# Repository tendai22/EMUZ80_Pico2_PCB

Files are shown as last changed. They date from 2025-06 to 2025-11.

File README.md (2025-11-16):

# EMUZ80_Pico2_PCB
KiCad PCB for emuz80_pico2

## WeAct RP2350B Core Board での動作

GPIO23を D7 に割り当てているが、D7 だけ L に落ちてくれない。

一瞬 L になるが、次の瞬間に H に戻っている。

blink で GPIO23 を指定したときは動作している。

Pimoroni 2350 の試作基板では動作している。

ハードウェアの違いによると考えられる。

基板の配線違いか、5.1kΩのプルアップが悪さをしていると考えた。

導通を見る限り怪しいところとつながっている様子はない。

結局 5.1kΩプルアップ抵抗をちぎり取って動作するようになった。なんとも。

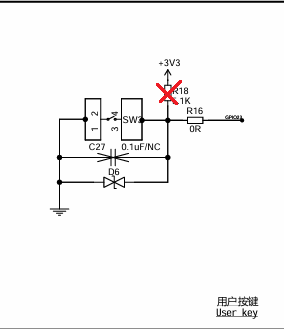
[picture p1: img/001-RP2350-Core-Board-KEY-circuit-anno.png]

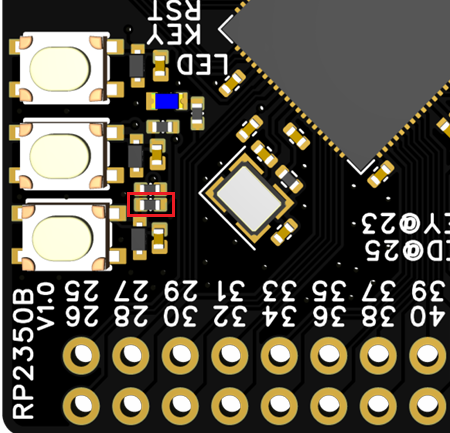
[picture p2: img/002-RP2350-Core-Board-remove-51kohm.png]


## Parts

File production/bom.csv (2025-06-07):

Designator | Footprint | Quantity | Value | LCSC Part #
C1, C2, C3, C4, C5 | C_Disc_D3.0mm_W1.6mm_P2.50mm | 5 | 0.1u
C7 | CP_Radial_D5.0mm_P2.50mm | 1 | 10uF
D1, D5 | D_DO-34_SOD68_P7.62mm_Horizontal | 2 | 1S3
D2 | LED_D3.0mm | 1 | RED
D3 | LED_D3.0mm | 1 | GREEN
D4 | LED_D3.0mm | 1 | YELLOW
J3 | PinHeader_1x08_P2.54mm_Vertical | 1 | EXT_GPIO1
J4 | PinHeader_1x02_P2.54mm_Vertical | 1 | EXT_GPIO2
J5 | PinHeader_1x06_P2.54mm_Horizontal_NoFeet | 1 | Serial
J6 | USB_Micro-B_Hirose_ZX62-B-5PA | 1 | USB_B_Micro
J8 | PinHeader_1x05_P2.54mm_Vertical | 1 | Conn_01x05_Pin
JP1 | SolderJumper-2_P1.3mm_Bridged_RoundedPad1.0x1.5mm | 1 | VCC_Jumper
JP2 | SolderJumper-2_P1.3mm_Bridged_RoundedPad1.0x1.5mm | 1 | CE1_J
JP3 | SolderJumper-2_P1.3mm_Bridged_RoundedPad1.0x1.5mm | 1 | CS2_J
JP4 | SolderJumper-2_P1.3mm_Bridged_RoundedPad1.0x1.5mm | 1 | OE_J
JP5 | SolderJumper-2_P1.3mm_Bridged_RoundedPad1.0x1.5mm | 1 | WE_J
R1, R2, R3 | R_Axial_L5.5mm_D2.0mm_P7.62mm_Horizontal | 3 | 1k
R4 | R_Axial_L5.5mm_D2.0mm_P7.62mm_Horizontal | 1 | 10k
SW1 | Tact_SW | 1 | RUN
SW2 | Tact_SW | 1 | BOOTSEL
U1 | PLCC-64_THT-Socket | 1 | Pimoroni PGA2350B
U2 | RB2350B_Core_Board | 1 | RB2350B_Core_Board
U3 | DIP-14_W7.62mm_Socket | 1 | 74HC00
U4 | DIP-40_SidePin_Z80 | 1 | Z80CPU
U5 | DIP-32_W15.24mm_OvalPads | 1 | HM628128

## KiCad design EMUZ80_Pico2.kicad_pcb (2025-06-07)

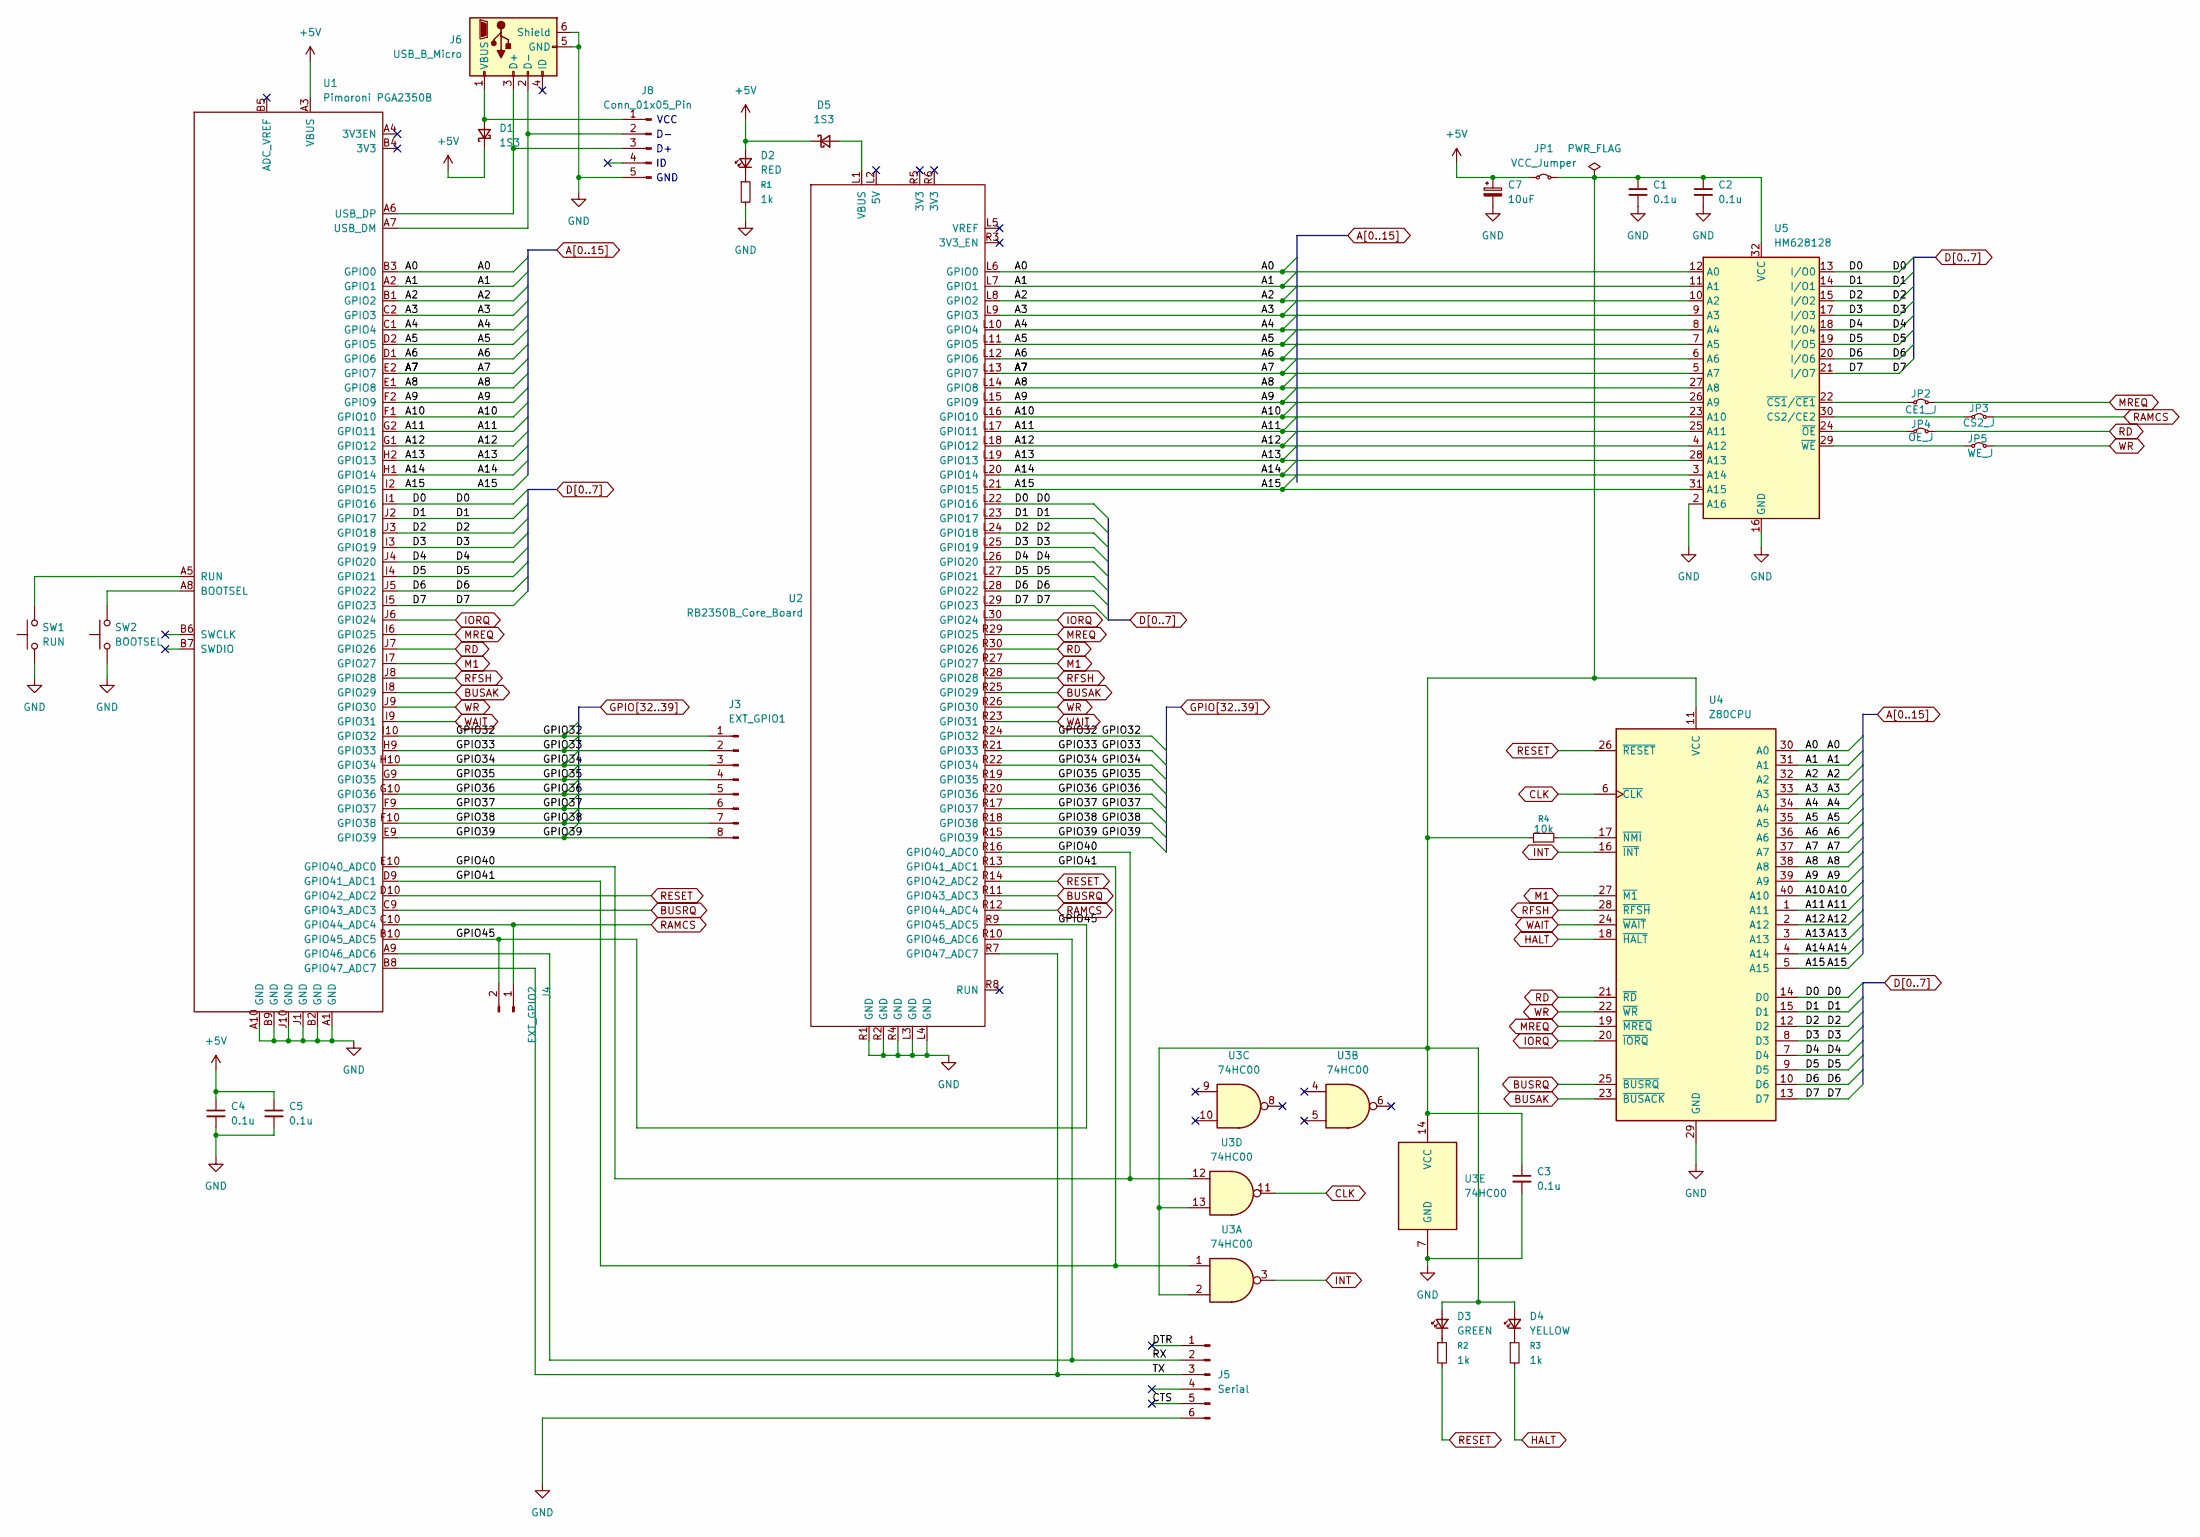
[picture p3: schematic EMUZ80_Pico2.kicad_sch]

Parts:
C1, C2, C3, C4, C5: 0.1u; C_Disc_D3.0mm_W1.6mm_P2.50mm
C7: 10uF; CP_Radial_D5.0mm_P2.50mm
D1, D5: 1S3; D_DO-34_SOD68_P7.62mm_Horizontal
D2: RED; LED_D3.0mm
D3: GREEN; LED_D3.0mm
D4: YELLOW; LED_D3.0mm
J3: EXT_GPIO1; PinHeader_1x08_P2.54mm_Vertical
J4: EXT_GPIO2; PinHeader_1x02_P2.54mm_Vertical
J5: Serial; PinHeader_1x06_P2.54mm_Horizontal_NoFeet
J6: USB_B_Micro; USB_Micro-B_Hirose_ZX62-B-5PA
J8: Conn_01x05_Pin; PinHeader_1x05_P2.54mm_Vertical
JP1: VCC_Jumper; SolderJumper-2_P1.3mm_Bridged_RoundedPad1.0x1.5mm
JP2: CE1_J; SolderJumper-2_P1.3mm_Bridged_RoundedPad1.0x1.5mm
JP3: CS2_J; SolderJumper-2_P1.3mm_Bridged_RoundedPad1.0x1.5mm
JP4: OE_J; SolderJumper-2_P1.3mm_Bridged_RoundedPad1.0x1.5mm
JP5: WE_J; SolderJumper-2_P1.3mm_Bridged_RoundedPad1.0x1.5mm
R1, R2, R3: 1k; R_Axial_L5.5mm_D2.0mm_P7.62mm_Horizontal
R4: 10k; R_Axial_L5.5mm_D2.0mm_P7.62mm_Horizontal
SW1: RUN; Tact_SW
SW2: BOOTSEL; Tact_SW
U1: Pimoroni PGA2350B; PLCC-64_THT-Socket
U2: RB2350B_Core_Board
U3: 74HC00; DIP-14_W7.62mm_Socket
U4: Z80CPU; DIP-40_SidePin_Z80
U5: HM628128; DIP-32_W15.24mm_OvalPads

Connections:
+5V: C4.1, C5.1, C7.1, D1.1 (K), D2.2 (A), D5.1 (K), JP1.1 (A), U1.A3 (VBUS)
/CTS: J5.5
/DTR: J5.1
/GPIO40: U1.E10 (GPIO40_ADC0), U2.R16 (GPIO40_ADC0), U3.12
/GPIO41: U1.D9 (GPIO41_ADC1), U2.R13 (GPIO41_ADC1), U3.1
/GPIO45: J4.2, U1.B10 (GPIO45_ADC5), U2.R9 (GPIO45_ADC5)
/RX: J5.2, U1.A9 (GPIO46_ADC6), U2.R10 (GPIO46_ADC6)
/TX: J5.3, U1.B8 (GPIO47_ADC7), U2.R7 (GPIO47_ADC7)
A0: U1.B3 (GPIO0), U2.L6 (GPIO0), U4.30 (A0), U5.12 (A0)
A1: U1.A2 (GPIO1), U2.L7 (GPIO1), U4.31 (A1), U5.11 (A1)
A2: U1.B1 (GPIO2), U2.L8 (GPIO2), U4.32 (A2), U5.10 (A2)
A3: U1.C2 (GPIO3), U2.L9 (GPIO3), U4.33 (A3), U5.9 (A3)
A4: U1.C1 (GPIO4), U2.L10 (GPIO4), U4.34 (A4), U5.8 (A4)
A5: U1.D2 (GPIO5), U2.L11 (GPIO5), U4.35 (A5), U5.7 (A5)
A6: U1.D1 (GPIO6), U2.L12 (GPIO6), U4.36 (A6), U5.6 (A6)
A7: U1.E2 (GPIO7), U2.L13 (GPIO7), U4.37 (A7), U5.5 (A7)
A8: U1.E1 (GPIO8), U2.L14 (GPIO8), U4.38 (A8), U5.27 (A8)
A9: U1.F2 (GPIO9), U2.L15 (GPIO9), U4.39 (A9), U5.26 (A9)
A10: U1.F1 (GPIO10), U2.L16 (GPIO10), U4.40 (A10), U5.23 (A10)
A11: U1.G2 (GPIO11), U2.L17 (GPIO11), U4.1 (A11), U5.25 (A11)
A12: U1.G1 (GPIO12), U2.L18 (GPIO12), U4.2 (A12), U5.4 (A12)
A13: U1.H2 (GPIO13), U2.L19 (GPIO13), U4.3 (A13), U5.28 (A13)
A14: U1.H1 (GPIO14), U2.L20 (GPIO14), U4.4 (A14), U5.3 (A14)
A15: U1.I2 (GPIO15), U2.L21 (GPIO15), U4.5 (A15), U5.31 (A15)
BUSAK: U1.I8 (GPIO29), U2.R25 (GPIO29), U4.23 (~BUSACK)
BUSRQ: U1.C9 (GPIO43_ADC3), U2.R11 (GPIO43_ADC3), U4.25 (~BUSRQ)
CLK: U3.11, U4.6 (~CLK)
D0: U1.I1 (GPIO16), U2.L22 (GPIO16), U4.14 (D0), U5.13 (I/O0)
D1: U1.J2 (GPIO17), U2.L23 (GPIO17), U4.15 (D1), U5.14 (I/O1)
D2: U1.J3 (GPIO18), U2.L24 (GPIO18), U4.12 (D2), U5.15 (I/O2)
D3: U1.I3 (GPIO19), U2.L25 (GPIO19), U4.8 (D3), U5.17 (I/O3)
D4: U1.J4 (GPIO20), U2.L26 (GPIO20), U4.7 (D4), U5.18 (I/O4)
D5: U1.I4 (GPIO21), U2.L27 (GPIO21), U4.9 (D5), U5.19 (I/O5)
D6: U1.J5 (GPIO22), U2.L28 (GPIO22), U4.10 (D6), U5.20 (I/O6)
D7: U1.I5 (GPIO23), U2.L29 (GPIO23), U4.13 (D7), U5.21 (I/O7)
GND: C1.2, C2.2, C3.2, C4.2, C5.2, C7.2, J5.6, J6.5 (GND), J6.6 (Shield), J8.5, R1.2, SW1.1, SW2.1, U1.A1 (GND), U1.A10 (GND), U1.B2 (GND), U1.B9 (GND), U1.J1 (GND), U1.J10 (GND), U2.L3 (GND), U2.L4 (GND), U2.R1 (GND), U2.R2 (GND), U2.R4 (GND), U3.7 (GND), U4.29 (GND), U5.2 (A16), U5.16 (GND)
GPIO32: J3.1, U1.I10 (GPIO32), U2.R24 (GPIO32)
GPIO33: J3.2, U1.H9 (GPIO33), U2.R21 (GPIO33)
GPIO34: J3.3, U1.H10 (GPIO34), U2.R22 (GPIO34)
GPIO35: J3.4, U1.G9 (GPIO35), U2.R19 (GPIO35)
GPIO36: J3.5, U1.G10 (GPIO36), U2.R20 (GPIO36)
GPIO37: J3.6, U1.F9 (GPIO37), U2.R17 (GPIO37)
GPIO38: J3.7, U1.F10 (GPIO38), U2.R18 (GPIO38)
GPIO39: J3.8, U1.E9 (GPIO39), U2.R15 (GPIO39)
HALT: R3.2, U4.18 (~HALT)
INT: U3.3, U4.16 (~INT)
IORQ: U1.J6 (GPIO24), U2.L30 (GPIO24), U4.20 (~IORQ)
M1: U1.I7 (GPIO27), U2.R27 (GPIO27), U4.27 (~M1)
MREQ: JP2.2 (B), U1.I6 (GPIO25), U2.R29 (GPIO25), U4.19 (~MREQ)
unnamed: D1.2 (A), J6.1 (VBUS), J8.1
unnamed: D2.1 (K), R1.1
unnamed: C1.1, C2.1, C3.1, D3.2 (A), D4.2 (A), JP1.2 (B), R4.1, U3.2, U3.13, U3.14 (VCC), U4.11 (VCC), U5.32 (VCC)
unnamed: D3.1 (K), R2.1
unnamed: D4.1 (K), R3.1
unnamed: D5.2 (A), U2.L1 (VBUS)
unnamed: J6.3 (D+), J8.3, U1.A6 (USB_DP)
unnamed: J6.2 (D-), J8.2, U1.A7 (USB_DM)
unnamed: JP2.1 (A), U5.22 (~CS1/~CE1)
unnamed: JP3.1 (A), U5.30 (CS2/CE2)
unnamed: JP4.1 (A), U5.24 (~OE)
unnamed: JP5.1 (A), U5.29 (~WE)
unnamed: SW2.2, U1.A8 (BOOTSEL)
unnamed: SW1.2, U1.A5 (RUN)
unnamed: R4.2, U4.17 (~NMI)
RAMCS: J4.1, JP3.2 (B), U1.C10 (GPIO44_ADC4), U2.R12 (GPIO44_ADC4)
RD: JP4.2 (B), U1.J7 (GPIO26), U2.R30 (GPIO26), U4.21 (~RD)
RESET: R2.2, U1.D10 (GPIO42_ADC2), U2.R14 (GPIO42_ADC2), U4.26 (~RESET)
RFSH: U1.J8 (GPIO28), U2.R28 (GPIO28), U4.28 (~RFSH)
WAIT: U1.I9 (GPIO31), U2.R23 (GPIO31), U4.24 (~WAIT)
WR: JP5.2 (B), U1.J9 (GPIO30), U2.R26 (GPIO30), U4.22 (~WR)

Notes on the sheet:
GND
VCC

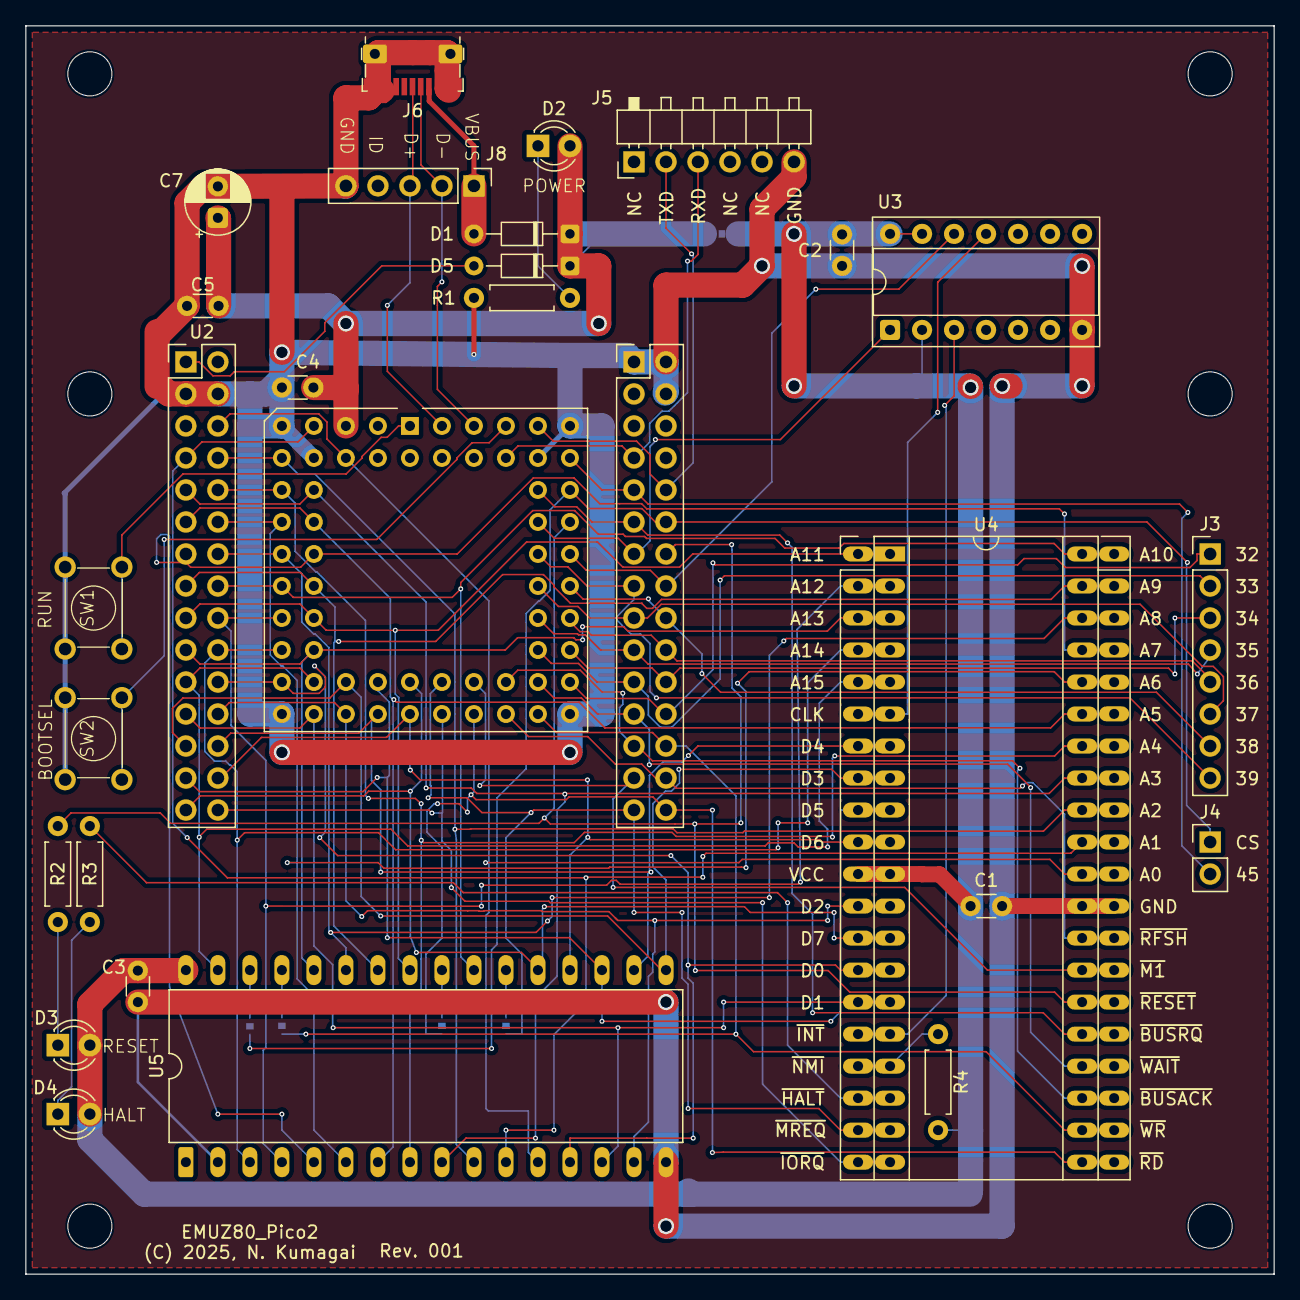
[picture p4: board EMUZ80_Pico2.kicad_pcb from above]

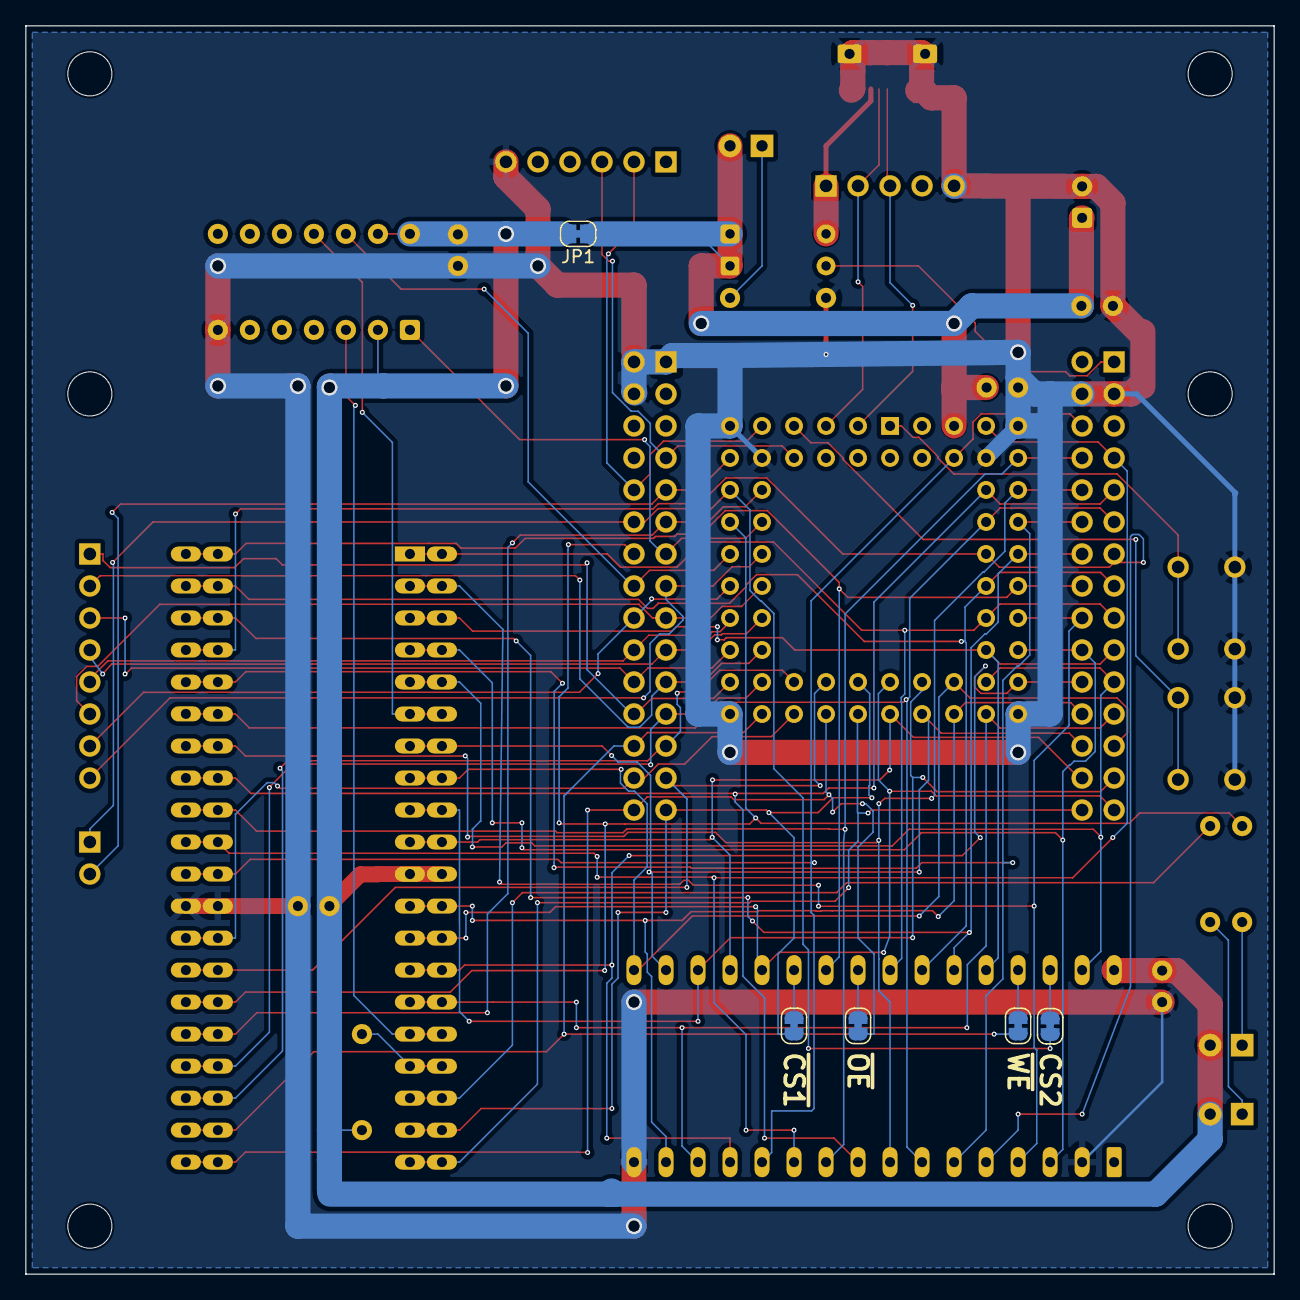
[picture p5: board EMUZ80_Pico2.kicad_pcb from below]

Board: 2 copper layers, 99.1 x 99.1 mm, 38 parts (5 on the bottom side), 68 nets.

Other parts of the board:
H1, H2, H3, H4, H5, H6: MountingHole; MountingHole_3.5mm

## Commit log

2025-06-03 add essential files
    [EMUZ80_Pico2.kicad_pcb, EMUZ80_Pico2.kicad_sch]
2025-06-03 schematic finished
    [EMUZ80_Pico2.kicad_sch]
2025-06-04 imported two DIP-40 footprints and one 1x20 PinHeader footprint
2025-06-04 schematic done, pcb now working
    [EMUZ80_Pico2.kicad_pcb, EMUZ80_Pico2.kicad_sch]
2025-06-05 EMUZ80_Pico2: PCB routing completed, ready to order
    [EMUZ80_Pico2.kicad_pcb, EMUZ80_Pico2.kicad_sch, EMUZ80_Pico2_poweronly.kicad_pcb]
2025-06-06 PCB rev001 finished, ready to order JLCPCB
    [EMUZ80_Pico2.kicad_pcb, EMUZ80_Pico2.kicad_sch, EMUZ80_Pico2_01mm.kicad_pcb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]
2025-06-07 add JP2-5 to SRAM Controls
    [EMUZ80_Pico2.kicad_pcb, EMUZ80_Pico2.kicad_sch]
2025-06-07 Rev001: order data
    [EMUZ80_Pico2.kicad_pcb, EMUZ80_Pico2.kicad_sch, bom.csv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]
2025-11-16 RP2350B Core Board does not work will, remove 5.1k R on the RP2305B Core Board, bad behavior

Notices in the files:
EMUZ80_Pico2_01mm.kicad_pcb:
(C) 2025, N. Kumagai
